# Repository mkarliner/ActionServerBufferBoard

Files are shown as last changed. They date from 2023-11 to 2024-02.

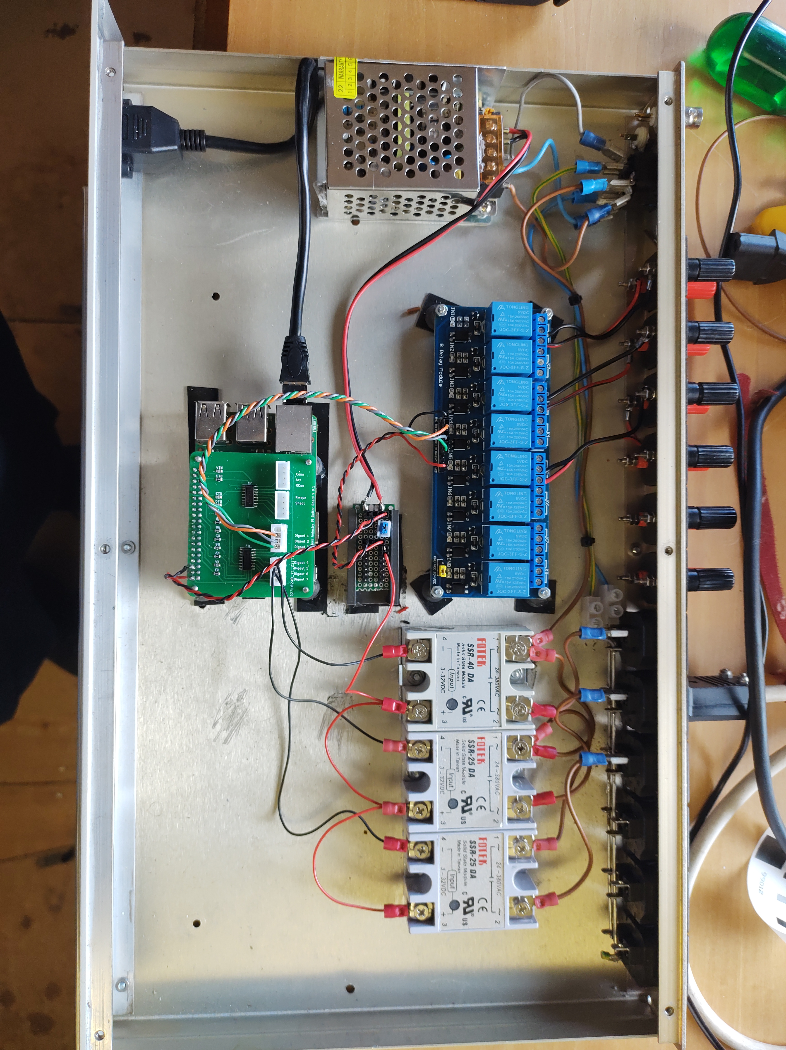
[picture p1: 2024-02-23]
board-installed.jpeg

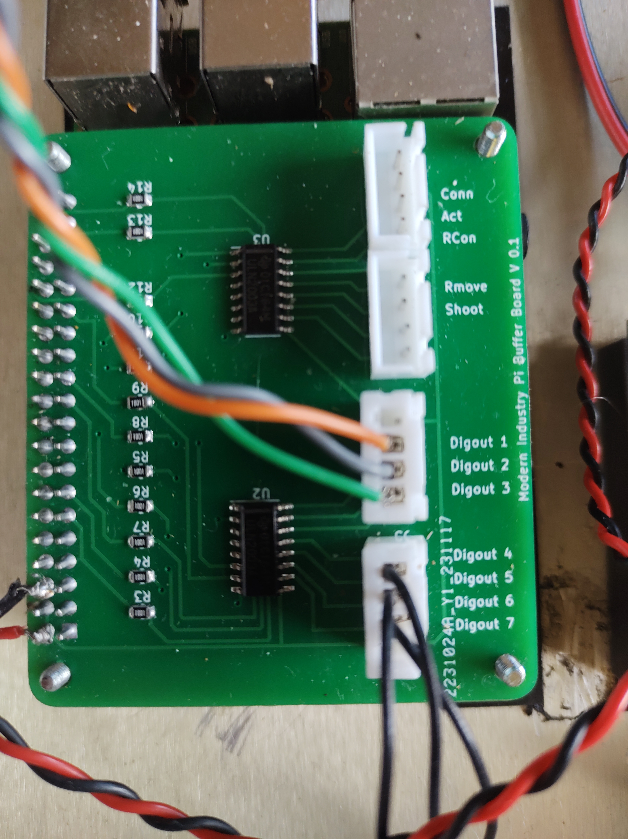
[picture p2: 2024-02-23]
board-close-up.jpeg

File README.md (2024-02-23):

This is a design for a board to buffer the outputs of a Raspberr Pi so that it can drive 5V devices which use up to 500ma. The buffer chips are ULN2003's which are Darlington pair arrays with open collector outputs. This means that they form low side switches. There are many articles on Google for using ULN2003's so I won't detail wiring here. The silkscreen is marked for the connections for the Camerabotics Lensmaster ActionServer to make it easier to wire up.

PLEASE NOTE: This is a first version of this design. I'm working on a second revision with more/easier connections and push/pull outputs. However, you are welcome to use this if you find it useful.

I've included pictures of the assembled board and my initial installation. The installation has three relay outputs and three 240V solid state relays. (The relay board has 8 relays of which one three are used)

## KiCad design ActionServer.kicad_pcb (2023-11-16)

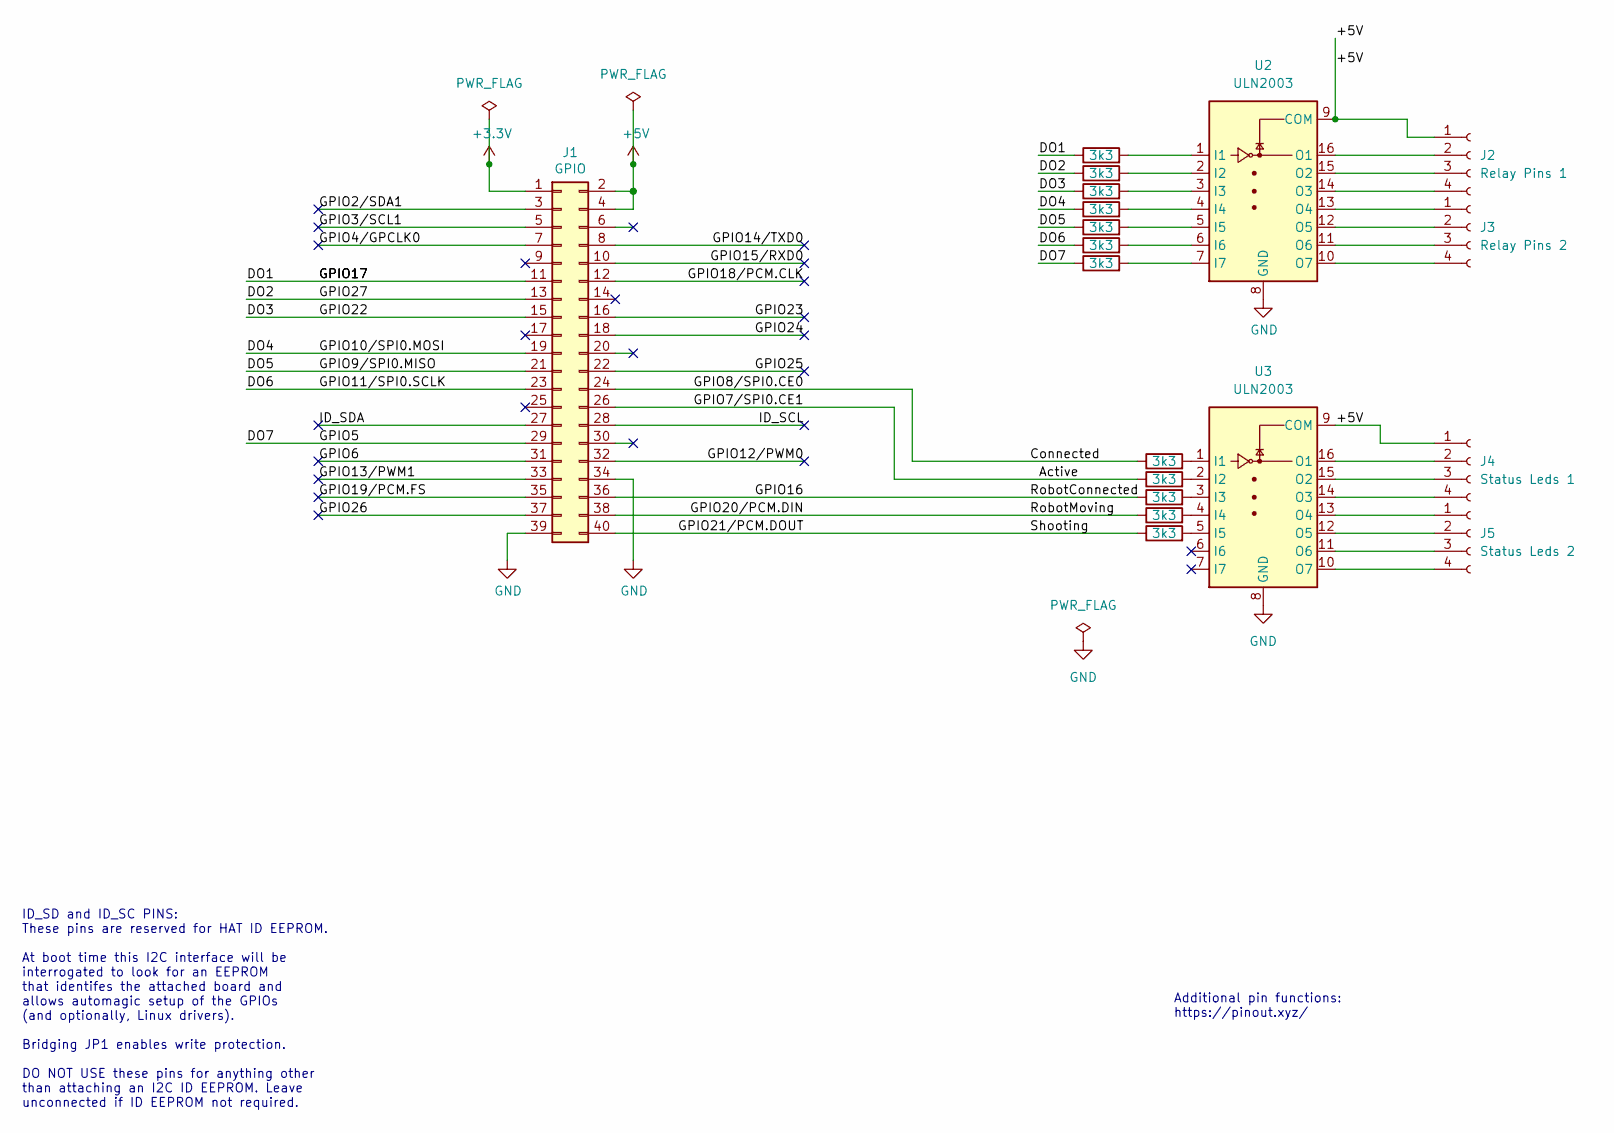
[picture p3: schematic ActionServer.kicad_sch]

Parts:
J1: GPIO; PinSocket_2x20_P2.54mm_Vertical
J2: Relay Pins 1; PinHeader_1x04_P2.54mm_Vertical
J3: Relay Pins 2; PinHeader_1x04_P2.54mm_Vertical
J4: Status Leds 1; PinHeader_1x04_P2.54mm_Vertical
J5: Status Leds 2; PinHeader_1x04_P2.54mm_Vertical
R3, R4, R5, R6, R7, R8, R9, R10, R11, R12, R13, R14: 3k3; R_0805_2012Metric
U2, U3: ULN2003; SOIC-16_3.9x9.9mm_P1.27mm

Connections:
+3.3V: J1.1
+5V: J1.2, J1.4, J2.1, J4.1, U2.9 (COM), U3.9 (COM)
/Active: J1.26, R11.1
/Connected: J1.24, R10.1
/DO1: J1.11, R3.1
/DO2: J1.13, R4.1
/DO3: J1.15, R5.1
/DO4: J1.19, R6.1
/DO5: J1.21, R7.1
/DO6: J1.23, R8.1
/DO7: J1.29, R9.1
/GPIO2/SDA1: J1.3
/GPIO3/SCL1: J1.5
/GPIO4/GPCLK0: J1.7
/GPIO6: J1.31
/GPIO12/PWM0: J1.32
/GPIO13/PWM1: J1.33
/GPIO14/TXD0: J1.8
/GPIO15/RXD0: J1.10
/GPIO16: J1.36, R12.1
/GPIO18/PCM.CLK: J1.12
/GPIO19/PCM.FS: J1.35
/GPIO20/PCM.DIN: J1.38, R13.1
/GPIO21/PCM.DOUT: J1.40, R14.1
/GPIO23: J1.16
/GPIO24: J1.18
/GPIO25: J1.22
/GPIO26: J1.37
/ID_SCL: J1.28
/ID_SDA: J1.27
GND: J1.34, J1.39, U2.8 (GND), U3.8 (GND)
unnamed: J2.2, U2.16 (O1)
unnamed: J2.3, U2.15 (O2)
unnamed: J2.4, U2.14 (O3)
unnamed: J3.1, U2.13 (O4)
unnamed: J3.2, U2.12 (O5)
unnamed: J3.3, U2.11 (O6)
unnamed: J3.4, U2.10 (O7)
unnamed: J4.2, U3.16 (O1)
unnamed: J4.3, U3.15 (O2)
unnamed: J4.4, U3.14 (O3)
unnamed: J5.1, U3.13 (O4)
unnamed: J5.2, U3.12 (O5)
unnamed: J5.3, U3.11 (O6)
unnamed: J5.4, U3.10 (O7)
unnamed: R3.2, U2.1 (I1)
unnamed: R4.2, U2.2 (I2)
unnamed: R5.2, U2.3 (I3)
unnamed: R6.2, U2.4 (I4)
unnamed: R7.2, U2.5 (I5)
unnamed: R8.2, U2.6 (I6)
unnamed: R9.2, U2.7 (I7)
unnamed: R10.2, U3.1 (I1)
unnamed: R11.2, U3.2 (I2)
unnamed: R12.2, U3.3 (I3)
unnamed: R13.2, U3.4 (I4)
unnamed: R14.2, U3.5 (I5)

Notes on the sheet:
Additional pin functions: https://pinout.xyz/
ID_SD and ID_SC PINS: These pins are reserved for HAT ID EEPROM. At boot time this I2C interface will be interrogated to look for an EEPROM that identifes the attached board and allows automagic setup of the GPIOs (and optionally, Linux drivers). Bridging JP1 enables write protection. DO NOT USE th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

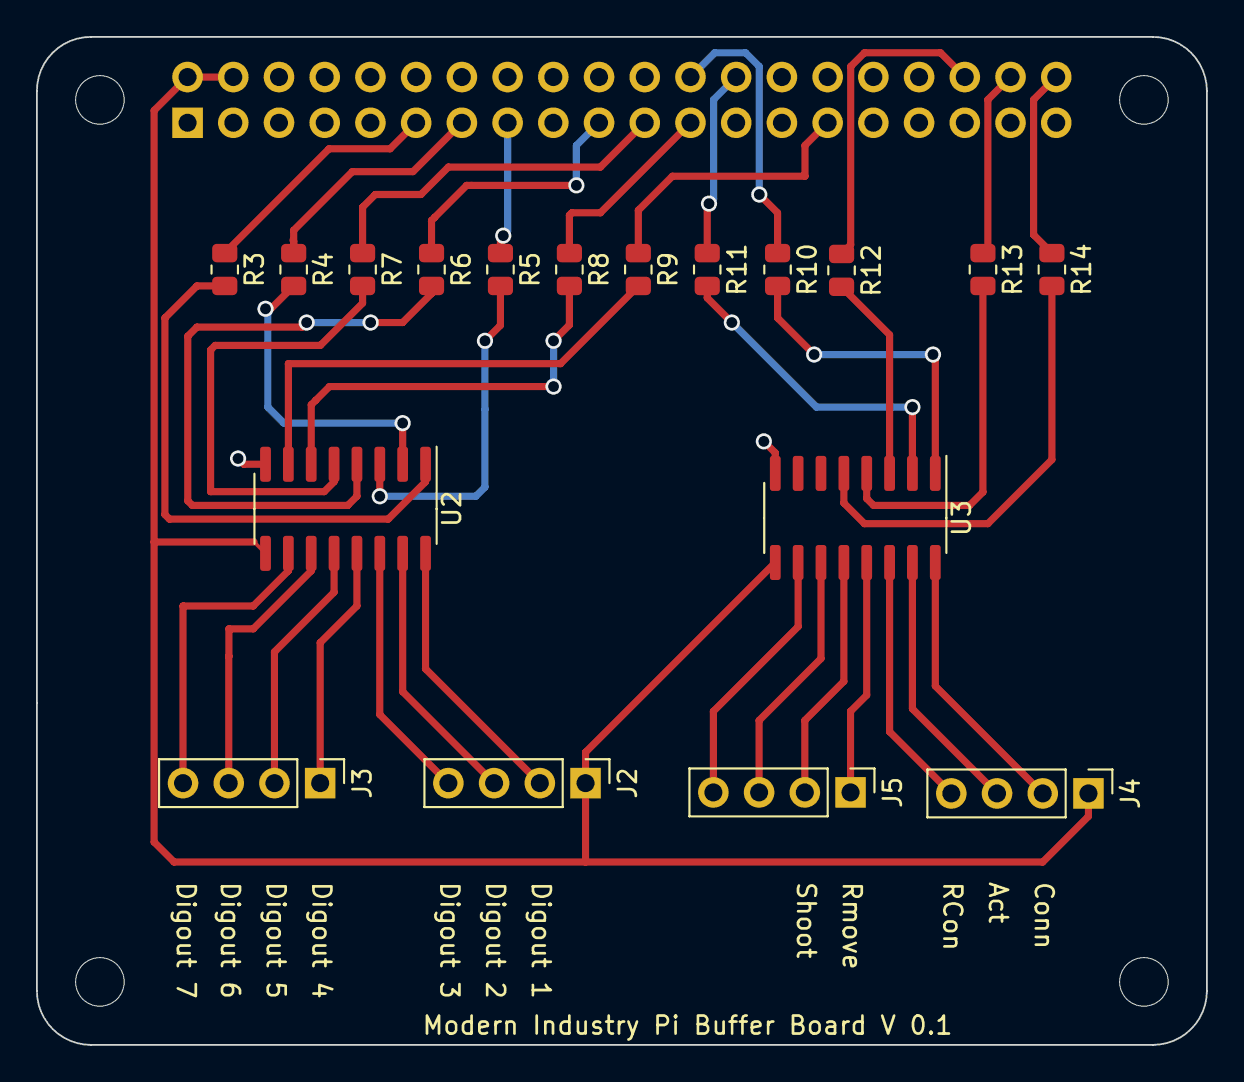
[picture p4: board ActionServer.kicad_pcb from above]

Board: 2 copper layers, 65.0 x 56.0 mm, 23 parts (1 on the bottom side), 40 nets.

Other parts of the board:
MH1, MH2, MH3, MH4: MountingHole_2.7mm_M2.5

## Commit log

2023-11-16 NEW: First check in
    [ActionServer.kicad_pcb, ActionServer.kicad_sch]
2023-11-16 CHANGE: Add plots folder
    [ActionServer-B_Cu.gbl, ActionServer-B_Silkscreen.gbo, ActionServer-F_Cu.gtl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]
2023-11-16 FIX: Output plot options
    [ActionServer-B_Cu.gbl, ActionServer-B_Mask.gbs, ActionServer-B_Paste.gbp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]
2024-02-23 Add files via upload
    Pictures of assembled and installed board
